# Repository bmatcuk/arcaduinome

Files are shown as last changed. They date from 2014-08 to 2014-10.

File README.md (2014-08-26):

# arcaduinome
Arcaduinome is an [Arduino](http://www.arduino.cc/) based MIDI controller that uses arcade buttons for input. The name is a combination of Arcade, Arduino, and [Monome](http://monome.org/).

1. [Software](#software)
2. [Hardware](#hardware)
  1. [Schematic](#schematic)
  2. [Board PCB Layout](#board-pcb-layout)
3. [Arduino Firmware](#arduino-firmware)
4. [License](#license)

## Software
The ArduinoSketch directory contains the Arduino source code. It requires that you have the MIDI Library installed. The latest build (at time of writing) is included in this repo. You'll first need to install it into your Arduino app: Open the Arduino application and select Sketch -> Import Library -> Add Library, then select Arduino_MIDI_Library_v4.1.zip.

## Hardware
Arcaduinome is based around the [Arduino Uno](http://arduino.cc/en/Main/ArduinoBoardUno), third revision. Most of the other hardware components are to support the LEDs which light the arcade buttons. Each component links to a website where you could buy the part, but you can probably find most of these parts at a variety of distributors. A lot of these parts could be swapped out for similar parts. I've made some notes below about why I've chosen a specific part and whether or not you can use some other generic part.

Datasheets for some of these parts can be found in the `reference` directory of this repository.

* **[Arduino Uno R3](http://www.adafruit.com/products/50)**
    I highly recommend a 3rd Revision (R3) board here. The R3 board has a larger USB-to-serial microcontroller (Atmega16U2) which will be reprogrammed later. If you have an older R1 or R2 board, you'll need to reprogram the USB-to-serial microcontroller every time you need to switch between MIDI and Arduino mode. Very annoying. With the R3, you just jumper two pins to switch back to Arduino mode.

* **16x [Sanwa OBSC 24 CW](http://www.paradisearcadeshop.com/sanwa-obsc-24mm-translucent-pushbuttons/689-sanwa-obsc-24-cw.html)**
    Any arcade button will do. Sanwa buttons are extremely popular with arcade cabinet and fighting game enthusiasts for their quick response and high-reliability. However, the buttons might be the most expensive part, so you can save a bit with some cheaper buttons. Just make sure they are translucent/transparent.

* **[Protoshield for Arduino](http://www.adafruit.com/products/51)**
    This part is optional. I like using the protoshield to break out the IO pins from the Arduino and it gives me a nice area to solder everything together. Plus, it's compact.

* **16x [Common Anode RGB LEDs](http://www.adafruit.com/products/302)**
    Theoretically, any RGB LEDs will do, as long as they are common-anode. You may need to adjust resistor values depending on the forward voltage of the LEDs you pick. Link goes to a 25-pack that's actually cheaper, I've found, than buying 16 discrete LEDs from other distributors. So save some money and you'll have 9 extra LEDs for your next project! Woot!

* **[Sanken SLA5086 - 5x P-Channel FET Array](http://www.digikey.com/product-search/en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)**
    The P-Channel FETs are used on the "high-side" of the LEDs to turn on the "rows". FETs are well-suited for this switching application, specifically P-Channels for the high-side. If every LED in a row is turned on, the high-side switch must be able to source ~0.24A. This part can handle 5A, so no problems there. Additionally, this particular part has a low (logic level) gate-threshold voltage, which means that it should fully "turn on" easily from the Arduino IO pin. All around, a good fit, and the hardest part to find alternatives for, unless you don't mind dealing with surface mount components. We're only going to use 4 of the 5 PFETs in this package, since we only have 4 rows of LEDs. And we're also going to use these rows to multiplex our buttons. This way, we only need to use 4 inputs for the 16 buttons.

* **2x [STMicroelectronics STPIC6D595B1R 8-bit Shift Register](http://www.digikey.com/product-detail/en/STPIC6D595B1R/497-6328-5-ND/1762207)**
    The shift registers are used on the "low-side" of the LEDs to control individual LEDs (ie, the columns). We need 2 of these because we have "12" LEDs per row (each RGB LED is basically like 3 LEDs - we have 4 RGB LEDs per row, so, 4 x 3 = 12). The two ICs are "daisy chained" to make a 16-bit shift register; we just ignore the last 4-bits since we only need 12. Each pin of the shift register must be able to sink 20mA, and, if every LED in the row is "on", the IC as a whole must be able to sink 8 x 20mA = 160mA. This IC can easily handle that with it's open-drain outputs. Additionally, the outputs are latched, which the code takes advantage of.

* **16x [NXP Semiconductors 1N4148,113 Standard Diode](http://www.digikey.com/product-detail/en/1N4148,113/568-1360-1-ND/763357)**
    Use any standard diodes you want, though lower forward voltages are preferable. These are just used to ensure that the buttons don't interfere with each other if you press two at the same time... particularly if they are in different rows.

* **8x [120 Ohm Resistors](http://www.digikey.com/product-detail/en/CFM14JT120R/S120QCT-ND/2617666)**
    Use any standard 120 Ohm resistors you like. These limit current through the green and blue sections of the RGB LEDs. If you use different RGB LEDs, make sure to use appropriate resistors! The RGB LEDs I'm using have a 3.2V forward voltage for the green and blue sections, so these resistors should limit current to somewhere around 15mA.

* **4x [220 Ohm Resistors](http://www.digikey.com/product-detail/en/CF14JT220R/CF14JT220RCT-ND/1830334)**
    Use any standard 220 Ohm resistors you like. These limit current through the red section of the RGB LEDs. If you use different RGB LEDs, make sure to use appropriate resistors! The RGB LEDs I'm using have a 1.8V forward voltage for the red section, so these resistors should limit current to somewhere around 15mA.

* **9x 4.7 kOhm Resistors**
    I had some of these laying around, so I don't have a link for them. The value is not very important, so any value around 4.7k is fine if you happen to have some resistors laying around, too. Though, you shouldn't have any trouble finding them on Digikey (or similar sites). These are just used as pull-up resistors for the Gates of the PFETs, and pull-down resistors for the buttons. The pull-up resistors will cause the PFETs to be shut-off when the circuit is first powered up, and the pull-down resistors will cause the Arduino to read 0's for the buttons until they are pressed. We need 5 of these resistors for the 5 PFETs in our array package (even though we are only using 4 of those PFETs, we want to make sure the 5th is "turned off"), and 4 resistors for the multiplexed buttons.

* **[12-pin SIP Socket](http://www.digikey.com/product-detail/en/643644-3/A29107-ND/294602)**
    Socket for the P-Channel FET Array - if you decide on some other high-side solution, you might not need this.

* **2x [16-pin DIP Socket](http://www.digikey.com/product-detail/en/A16-LC-TR-R/AE9994-ND/821748)**
    Sockets for the low-side shift registers - if you decide on some other low-side solution, you might not need this.

### Schematic

This is the full schematic for the Arcaduinome:

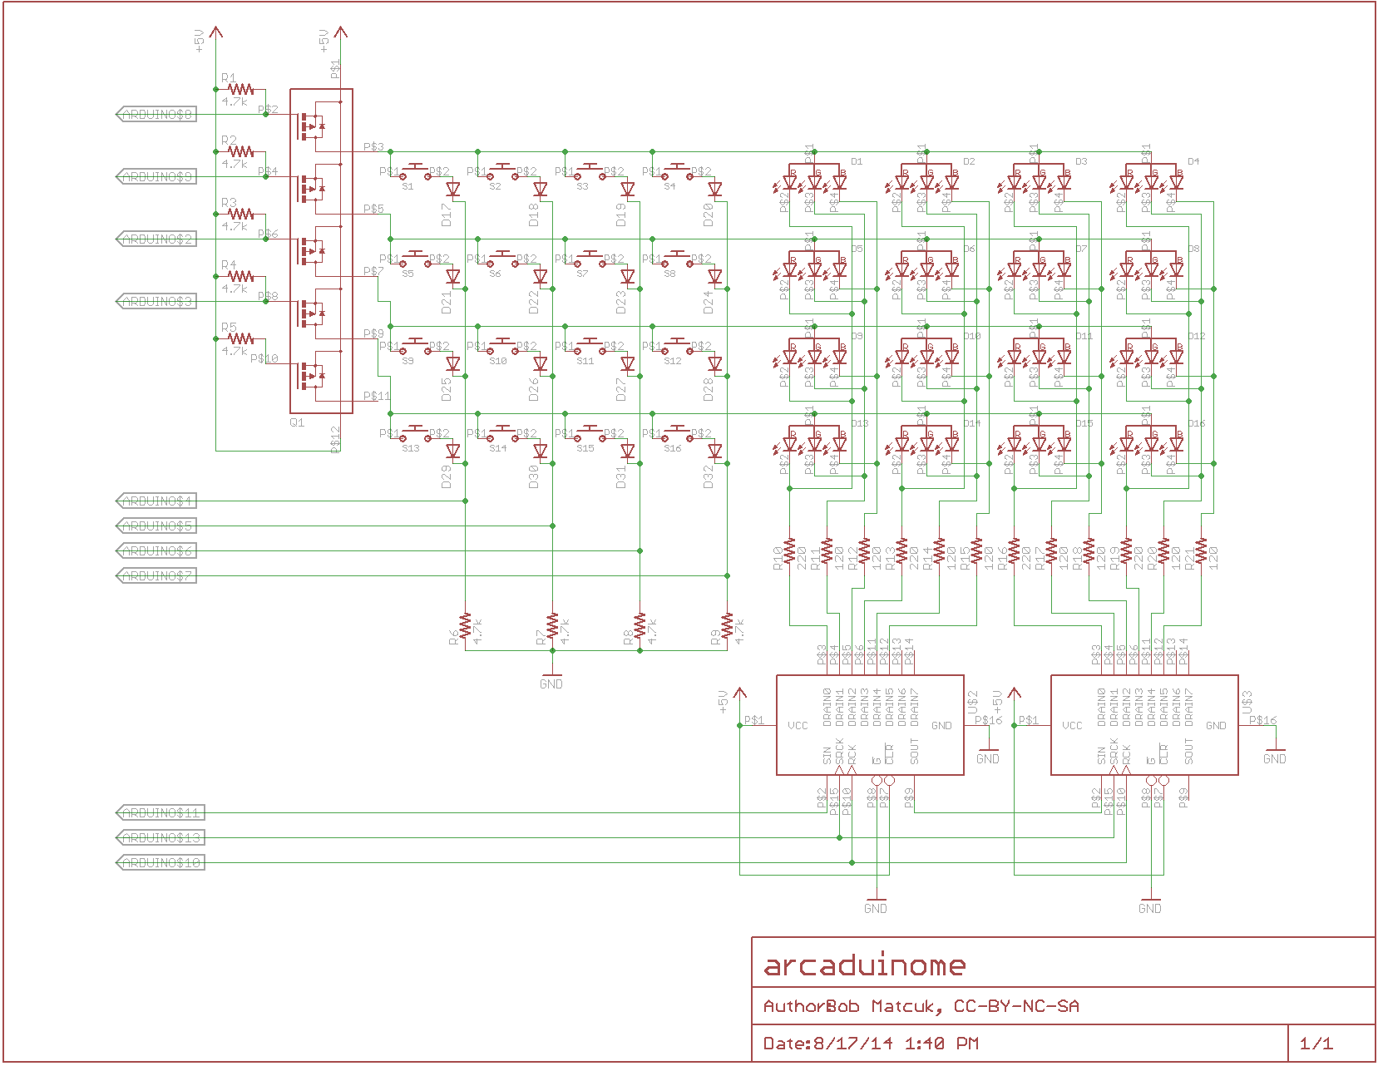
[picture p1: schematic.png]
Arcaduinome Schematic


However, due to limitations in the free version of Eagle and the fact that my PCB-manufacturer-of-choice is going to require that I order at least 3 boards anyway, I designed a smaller board that houses 4 buttons, with associated LEDs, resistors, and diodes, and a shift register:

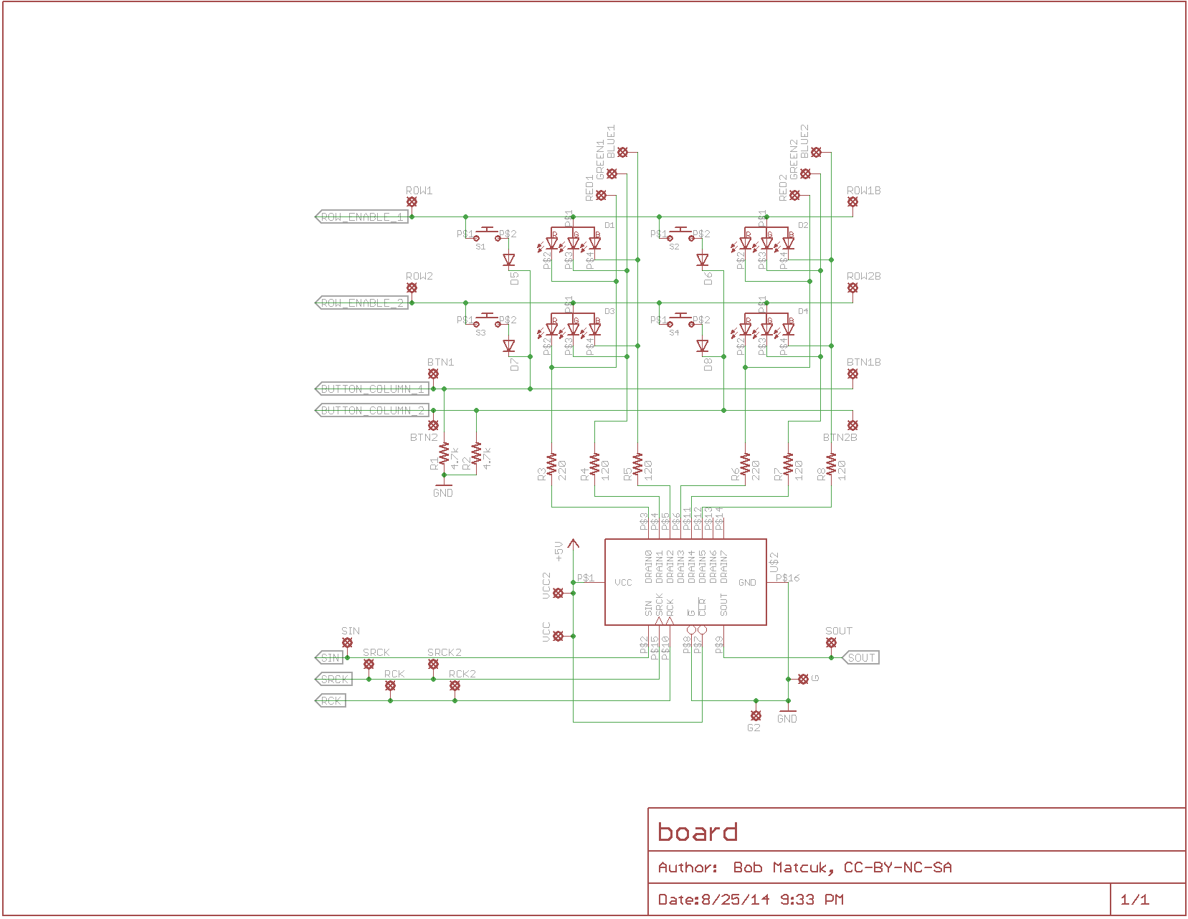
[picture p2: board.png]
Arcaduinome Board Schematic


The idea is that four of these boards would be used: the two boards at the "bottom" will house the shift registers. The two boards at the "top" will not have shift registers and, instead, use jumpers to connect to the boards on the "bottom". Similarly, jumpers are used to connect boards from left to right.

These schematics were generated using the free version of [Eagle v7.1](http://www.cadsoftusa.com/). The files are available in the `eagle` directory of this repository.

### Board PCB Layout

This is the layout of the smaller board I designed:

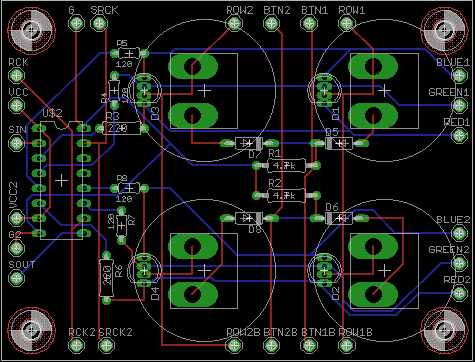
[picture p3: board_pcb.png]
Arcaduinome Board Layout


This layout was generated using the free version of [Eagle v7.1](http://www.cadsoftusa.com/). The files are available in the `eagle` directory of this repository.

## Arduino Firmware
The Arduino Uno R3 uses a microcontroller, specifically the Atmega16U2, as a USB-to-Serial adapter. Arcaduinome takes advantage of this fact using the [Moco](http://morecatlab.akiba.coocan.jp/lab/index.php/aruino/midi-firmware-for-arduino-uno-moco/?lang=en) (aka dualMocoLUFA) firmware. The latest version (at the time of writing) is included in this repo as dualMoco.hex. Installing this firmware on the Atmega16U2 will cause the Arduino to appear as a generic MIDI device to Windows/OSX. This way, we won't need any special drivers to interface with Arcaduinome.

To install the firmware into the Atmega16U2, follow the [DFU Programming Directions](http://arduino.cc/en/Hacking/DFUProgramming8U2) on Arduino's website. Once the new firmware has been installed, it will appear as a generic MIDI device when connected to your computer. You will no longer be able to use it as an Arduino (in other words, you won't be able to reprogram it). However, if you want to reenable Arduino mode, disconnect the Arduino from your computer, connect a jumper between pin 4 and 6 on the ICSP header, and reconnect to your computer. It should now appear as a normal Arduino Uno. When you're done reprogramming, disconnect from your computer, remove the jumper, and reconnect - it will now appear as a MIDI device again!

## License
This work is licensed under a [Creative Commons Attribution-NonCommercial-ShareAlike 4.0 International License](http://creativecommons.org/licenses/by-nc-sa/4.0/)



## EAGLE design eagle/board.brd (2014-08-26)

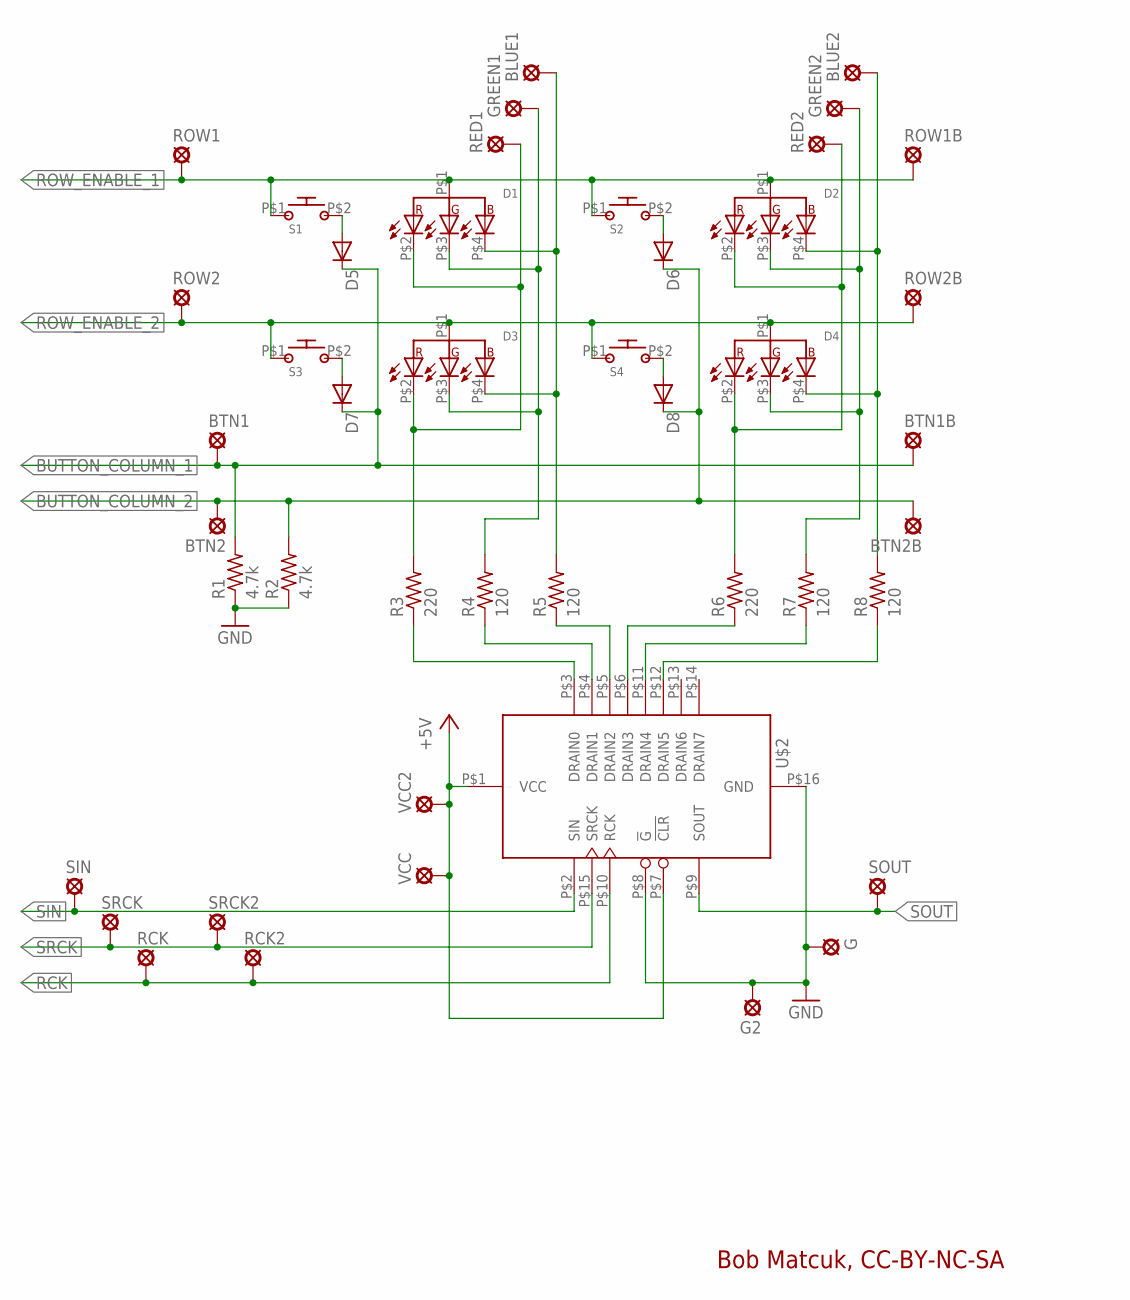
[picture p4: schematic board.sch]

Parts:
BLUE1, BLUE2: MCS10B
BTN1, BTN1B, BTN2, BTN2B: MCS10B
D1, D2, D3, D4: FD-5WSRGB-A; 5MM_RGB_LED
D5, D6, D7, D8: 1N4148DO35-7; DO35-7
G, G2: MCS10B
GREEN1, GREEN2: MCS10B
R1, R2: 4.7k; 0207/10
R3, R6: 220; 0207/7
R4, R5, R7, R8: 120; 0204/5
RCK, RCK2: MCS10B
RED1, RED2: MCS10B
ROW1, ROW1B, ROW2, ROW2B: MCS10B
S1, S2, S3, S4: SANWA_OBSC_24_CW; SANWA_24MM
SIN: MCS10B
SOUT: MCS10B
SRCK, SRCK2: MCS10B
U$2: STPIC6D595; DIP16
VCC, VCC2: MCS10B

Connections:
+5V: U$2.P$1 (VCC), U$2.P$7 (!CLR), VCC.MP, VCC2.MP
BUTTON_COLUMN_1: BTN1.MP, BTN1B.MP, D5.C, D7.C, R1.2
BUTTON_COLUMN_2: BTN2.MP, BTN2B.MP, D6.C, D8.C, R2.2
GND: G.MP, G2.MP, R1.1, R2.1, U$2.P$8 (!G), U$2.P$16 (GND)
unnamed: D5.A, S1.P$2
unnamed: D1.P$2 (R), D3.P$2 (R), R3.2, RED1.MP
unnamed: D1.P$3 (G), D3.P$3 (G), GREEN1.MP, R4.2
unnamed: BLUE1.MP, D1.P$4 (B), D3.P$4 (B), R5.2
unnamed: R5.1, U$2.P$5 (DRAIN2)
unnamed: D6.A, S2.P$2
unnamed: R4.1, U$2.P$4 (DRAIN1)
unnamed: D2.P$2 (R), D4.P$2 (R), R6.2, RED2.MP
unnamed: D2.P$3 (G), D4.P$3 (G), GREEN2.MP, R7.2
unnamed: BLUE2.MP, D2.P$4 (B), D4.P$4 (B), R8.2
unnamed: R3.1, U$2.P$3 (DRAIN0)
unnamed: D7.A, S3.P$2
unnamed: D8.A, S4.P$2
unnamed: R6.1, U$2.P$6 (DRAIN3)
unnamed: R7.1, U$2.P$11 (DRAIN4)
unnamed: R8.1, U$2.P$12 (DRAIN5)
RCK: RCK.MP, RCK2.MP, U$2.P$10 (RCK)
ROW_ENABLE_1: D1.P$1 (ANODE), D2.P$1 (ANODE), ROW1.MP, ROW1B.MP, S1.P$1, S2.P$1
ROW_ENABLE_2: D3.P$1 (ANODE), D4.P$1 (ANODE), ROW2.MP, ROW2B.MP, S3.P$1, S4.P$1
SIN: SIN.MP, U$2.P$2 (SIN)
SOUT: SOUT.MP, U$2.P$9 (SOUT)
SRCK: SRCK.MP, SRCK2.MP, U$2.P$15 (SRCK)

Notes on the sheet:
Bob Matcuk, CC-BY-NC-SA

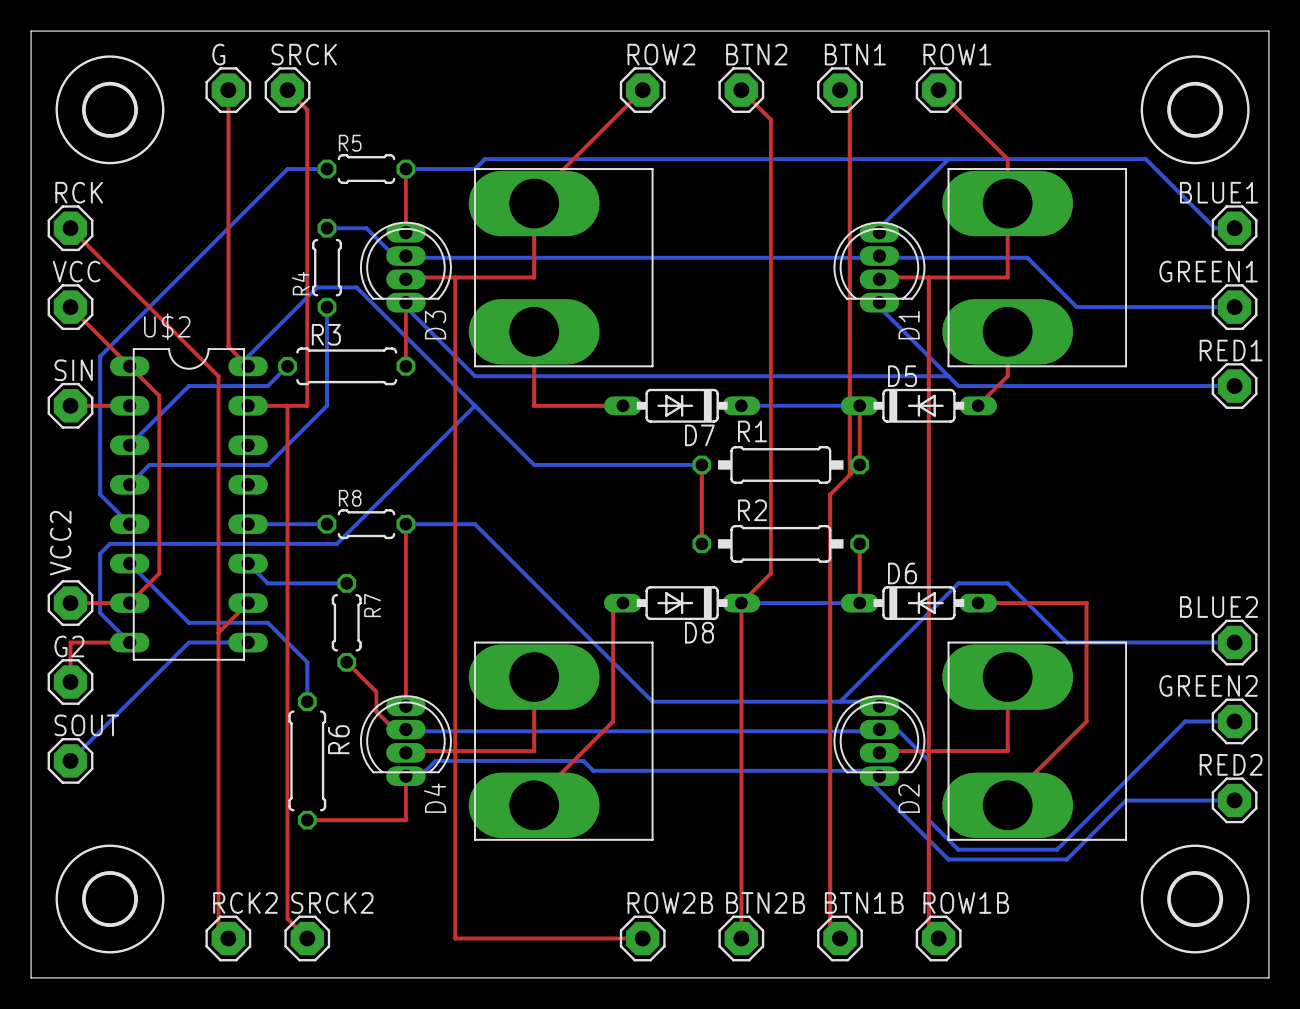
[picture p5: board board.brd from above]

Board: 2 copper layers, 79.7 x 61.0 mm, 49 parts (0 on the bottom side), 26 nets.

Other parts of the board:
U$3, U$4, U$5, U$6: 3,2

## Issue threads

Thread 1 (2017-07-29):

Still active?

ayman0201, 2017-07-29:
Hi,

I know the project is 3 years old, but I was still interested in implementing it.
I was trying the eagle folder files and none of them opened on eagle 7.1
Have you tried porting them into a newer version?

bmatcuk, 2017-07-29:
Hey there,

Thanks for the interest! Unfortunately, I never quite finished this project =( I'd really like to finish it up at some point, but I can't seem to find the time. It needs a lot of work: I think the Arduino code can only turn on the LEDs to preset colors, and there's some debounce code for the buttons, but that's about it. I really wanted to make the colors programmable, and I needed to write the MIDI stuff. Then I needed a desktop app that could be used to set the colors and notes - I didn't even start that. I was also thinking of redesigning the boards to use wires to the buttons, instead of trying to solder the buttons directly to the boards; I think that would make building it easier. And I wanted to design a 3D printed box for the whole thing. So many ideas, so little time =(

Man, I should really finish this...

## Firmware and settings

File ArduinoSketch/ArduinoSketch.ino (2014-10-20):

/*******************************************************************************
Arcaduinome Arduino Sketch
- Bob Matcuk, 2014

This code eschews things like pinMode and digitalWrite for speed reasons, and,
instead, accesses the registers directly using bit-wise operators. It's not
meant to look pretty; it's meant to handle the LEDs as quickly as possible,
since the MIDI stuff is much more important. Hopefully it's documented well
enough that you can follow along! =)

Atmega pin to Arduino mapping: http://arduino.cc/en/Hacking/PinMapping168
Arduino pin description: http://www.gammon.com.au/forum/?id=11473

TODO: buttons - http://www.ganssle.com/debouncing-pt2.htm (listing 3)
*******************************************************************************/

#include <EEPROM.h>
#include <MIDI.h>
#include <midi_Defs.h>
#include <midi_Namespace.h>
#include <midi_Settings.h>

// if defined, disables MIDI and just prints stuff to serial
//#define DEBUG 1

// The MIDI manufacturer ID is used to determine if a sysex message is
// destined for us. 0x7D is specifically reserved for "educational use", so it
// shouldn't be used by any commercial product. However, if you find that this
// is causing some problems with some other MIDI equipment, you might need to
// change this. The code does NOT support extended Manufacturer IDs (the MIDI
// spec includes support for an ID of 0x00 which means that the next two bytes
// are the actual ID), but it could be added...
#define MIDI_MANUFACTURER_ID 0x7D

// Sysex message IDs
#define SYSEX_SET_ALL_LEDS 0x00
#define SYSEX_SET_LED      0x01
#define SYSEX_SAVE_LEDS    0x02
#define SYSEX_RESET_LEDS   0x03

#define SYSEX_SET_ALL_BUTTONS 0x10
#define SYSEX_SET_BUTTON      0x11
#define SYSEX_SAVE_BUTTONS    0x12
#define SYSEX_RESET_BUTTONS   0x13

// Offsets in EEPROM for LED and Button settings
#define EEPROM_LED_OFFSET    0x0000
#define EEPROM_BUTTON_OFFSET (EEPROM_LED_OFFSET + 4 * 12)

// Multiplexed "rows" are controlled via the high-side P-channel FET Array.
// Only one row may be turned on at a time. Row 1 and 2 are controlled by
// Port B, pins 0 and 1. Row 3 and 4 are controlled by Port D, pins 2 and 3.
// To turn "on" a row, the corresponding pin must be brought LOW. Therefore,
// ROW_ENABLES has negated the masks already so they can be AND'd.
#define ROW1_ENABLE_MASK _BV(0)   // Arduino pin 8 = Port B, pin 0
#define ROW2_ENABLE_MASK _BV(1)   // Arduino pin 9 = Port B, pin 1
#define ROW3_ENABLE_MASK _BV(2)   // Arduino pin 2 = Port D, pin 2
#define ROW4_ENABLE_MASK _BV(3)   // Arduino pin 3 = Port D, pin 3
const byte ROW_ENABLES[] = {
  ~ROW1_ENABLE_MASK,
  ~ROW2_ENABLE_MASK,
  ~ROW3_ENABLE_MASK,
  ~ROW4_ENABLE_MASK
};

// SPI settings for the SPI Control Register:
// 0  = disable SPI Interupt
// 1  = enable SPI
// 1  = transfer LSB first
// 1  = master mode
// 0  = idle clock is low and pulses high
// 0  = sample on the leading edge of the clock
// 00 = speed is clock/4 (set LSB of SPSR to a 1 to double speed)
#define SPI_SETTINGS B01110000

// SPI output pins - SCK, MOSI, and SS
// SCK  = Arduino pin 13 = Port B, pin 5
// MOSI = Arduino pin 11 = Port B, pin 3
// SS   = Arduino pin 10 = Port B, pin 2
#define SPI_OUTPUT_PINS (_BV(5) | _BV(3) | _BV(2))

// LED array - 4 rows by 12 columns arranged in RGB order
// ie: {{R1, G1, B1, R2, G2, B2, R3, G3, B3, R4, G4, B4}, {...}, ...}
byte leds[4][12];

// Button inputs are the four high bits of Port D.
#define BUTTON1_MASK _BV(4)   // Arduino pin 4 = Port D, pin 4
#define BUTTON2_MASK _BV(5)   // Arduino pin 5 = Port D, pin 5
#define BUTTON3_MASK _BV(6)   // Arduino pin 6 = Port D, pin 6
#define BUTTON4_MASK _BV(7)   // Arduino pin 7 = Port D, pin 7
#define BUTTON_MASK  (BUTTON1_MASK | BUTTON2_MASK | BUTTON3_MASK | BUTTON4_MASK)
const byte BUTTON_MASKS[] = {
  BUTTON1_MASK,
  BUTTON2_MASK,
  BUTTON3_MASK,
  BUTTON4_MASK
};

// Debouncing array for buttons: the first dimension of the array represents
// rows. The second is a circular queue representing the last X many readings
// from Port D (where the buttons are - see above). X is DEBOUNCING_CHECKS
// and MUST be a power of 2. If all of these readings are identical, that
// means the user really did press (or release) the button. button_index
// holds the current index into the circular queue. Once it hits the maximum
// (DEBOUNCING_CHECKS), it will wrap back to zero.
#define DEBOUNCING_CHECKS 16
byte button_debounce[4][DEBOUNCING_CHECKS];
byte button_index = 0;

// We also keep track of the current state of the buttons... The cooresponding
// bit will be a 1 if we have already decided the button was pressed and sent
// the cooresponding "NoteOn" command. It'll be a zero if we think the button
// hasn't been pressed.
byte button_state[4];

// This array holds the note that a button should make when it is pressed.
byte buttons[4][4];


void setup()
{
  // Set "row" pins as output and turn them all off for now (by setting the
  // pins high). We set the pins high first, which will engage the internal
  // pull-up resistors since they're still in "input" mode. Externally, we
  // have more pull up resistors, so nothing will really happen. Then when
  // we switch to output mode, the pins will already be pulled high so more
  // nothing will happen - exactly as we planned =)
  PORTB |= ROW1_ENABLE_MASK | ROW2_ENABLE_MASK;
  DDRB |= ROW1_ENABLE_MASK | ROW2_ENABLE_MASK;
  PORTD |= ROW3_ENABLE_MASK | ROW4_ENABLE_MASK;
  DDRD |= ROW3_ENABLE_MASK | ROW4_ENABLE_MASK;
  
  // Set SPI pins to output and bring SS (Port B, pin 2) low
  DDRB |= SPI_OUTPUT_PINS;
  PORTB &= ~_BV(2);
  
  // Setup SPI to communicate with the shift registers for "columns"
  // The STPIC6D595B1R shift registers recommend a clock duration of at least
  // 40ns = 25MHz. The fastest SPI clock on the Arduino is clock/2 = 8MHz,
  // which is slower than the quickest clock the shift registers can handle.
  // To achieve clock/2, we must also set the LSB of SPSR to 1 to enable
  // "double speed". Ideas stolen from SPI library source:
  // https://github.com/arduino/Arduino/blob/master/libraries/SPI/SPI.cpp
  // https://github.com/arduino/Arduino/blob/master/libraries/SPI/SPI.h
  SPCR = SPI_SETTINGS;
  SPSR |= _BV(0);
  
  // Setup button input pins - shouldn't really need to do this, since
  // input is default... but for completeness...
  DDRD &= ~BUTTON_MASK;
  
  // Enable MIDI
#ifdef DEBUG
  Serial.begin(115200);
#else
  MIDI.begin();
  MIDI.turnThruOff();
  MIDI.setHandleSystemExclusive(handleSystemExclusive);
#endif
  
  // load LEDs from EEPROM
  //for (byte row = 0; row < 4; row++) {
  //  for (byte column = 0; column < 12; column++) {
  //    leds[row][column] = EEPROM.read(EEPROM_LED_OFFSET + (12 * row) + column);
  //  }
  //}
  
  // TODO: remove and uncomment above!
  // for testing, let's give the LED some colors!
  for (byte row = 0; row < 4; row++) {
    for (byte column = 0; column < 4; column++) {
      leds[row][column*3]   = min(256 - row * 64, 255);      // R
      leds[row][column*3+1] = min(256 - column * 64, 255);   // G
      leds[row][column*3+2] = 255;                           // B
    }
  }
  
  // zero out debouncing, button state, and load buttons
  for (byte row = 0; row < 4; row++) {
    button_state[row] = 0;
    for (byte column = 0; column < 4; column++)
      buttons[row][column] = 0;   // TODO: EEPROM.read(EEPROM_BUTTON_OFFSET + (4 * row) + column);
    for (byte checks = 0; checks < DEBOUNCING_CHECKS; checks++)
      button_debounce[row][checks] = 0;
  }
}

void handleSystemExclusive(byte *array, byte size)
{
  // array[0] will be 0xF0 which starts the sysex message
  // array[1] will be the manufacturer ID - ignore the message if it
  //   doesn't match our manufacturer ID
  // array[2] will be the operation, assuming the message is for us
  // array[3..size-2] will be the data encoded using the following scheme:
  //   bytes evenly divisible by 8 (0, 8, 16, ...) will represent the MSb
  //   of the following 7 bytes, with the LSb corresponding to the first
  //   byte, and the MSb corresponding to the 7th byte. This is because
  //   the MIDI standard reserves bytes that have the MSb set. This scheme
  //   allows us to encode values greater than 127 and is, conveniently,
  //   implemented by the Arduino MIDI library.
  // array[size-1] is 0xF7, the MIDI code for "end of sysex"
  // size includes the 0xF0 "start sysex" code, the manufacturer ID,
  //   the operation code, and the terminating 0xF7 code, so the actual
  //   data length is size - 4 starting at array + 3.
  if (array[1] == MIDI_MANUFACTURER_ID) {
    if (array[2] == SYSEX_SET_ALL_LEDS) {
      // Set All LEDs
      // leds is a 2D array, but C lays out 2D arrays like 1D arrays, so
      // we trick it into dumping the data in with a cast.
      midi::decodeSysEx(array + 3, (byte*)leds, size - 4);
    } else if (array[2] == SYSEX_SET_LED) {
      // Set an Individual LED Color
      // array[3..6] is R,G,B for the LED, encoded as described above (hence
      //   the extra byte)
      // array[7] is the row
      // array[8] is the column
      // Technically, array[7] and array[8] are part of the encoding as
      // described above, but since both row and column will be less than 4,
      // we don't need to worry about decoding their MSb.
      midi::decodeSysEx(array + 3, (byte*)leds + (12 * array[7] + 3 * array[8]), 4);
    } else if (array[3] == SYSEX_SAVE_LEDS) {
      // Save the LED Colors to the EEPROM
      for (byte i = 0; i < 4; i++) {
        for (byte j = 0; j < 12; j++) {
          EEPROM.write(EEPROM_LED_OFFSET + (12 * i) + j, leds[i][j]);
        }
      }
    } else if (array[3] == SYSEX_RESET_LEDS) {
      // Reset the LEDs from the EEPROM
      for (byte i = 0; i < 4; i++) {
        for (byte j = 0; j < 12; j++) {
          leds[i][j] = EEPROM.read(EEPROM_LED_OFFSET + (12 * i) + j);
        }
      }
    } else if (array[3] == SYSEX_SET_ALL_BUTTONS) {
      // Set All Buttons
      // buttons in a 2D array, but C lays out 2D arrays like 1D arrays, so
      // we trick it into dumping the data in with a cast.
      midi::decodeSysEx(array + 3, (byte*)buttons, size - 4);
    } else if (array[3] == SYSEX_SET_BUTTON) {
      // Set an Individual Button
      // array[3] will always be zero as a result of encoding
      // array[4] will be the note to use for the button
      // array[5] is the row
      // array[6] is the column
      buttons[array[5]][array[6]] = array[4];
    } else if (array[3] == SYSEX_SAVE_BUTTONS) {
      // Save the Buttons to the EEPROM
      for (byte i = 0; i < 4; i++) {
        for (byte j = 0; j < 4; j++) {
          EEPROM.write(EEPROM_BUTTON_OFFSET + (4 * i) + j, buttons[i][j]);
        }
      }
    } else if (array[3] == SYSEX_RESET_BUTTONS) {
      // Reset the buttons from the EEPROM
      for (byte i = 0; i < 4; i++) {
        for (byte j = 0; j < 4; j++) {
          buttons[i][j] = EEPROM.read(EEPROM_BUTTON_OFFSET + (4 * i) + j);
        }
      }
    }
  }
}

void loop()
{
  // The iteration count is used to vary LED intensity. If we have a red
  // value of 128, for example, we only turn that LED "on" for the first
  // half of the passes through the main loop. It's kind of like a poor
  // man's PWM.
  static byte last_row = 3, row = 0, iteration_count = 0;
  
  // read MIDI data
#ifdef DEBUG
#else
  MIDI.read();
#endif
  
  // The shift registers are configured so that RGB LED 1 is on pins
  // 0 = R, 1 = G, 2 = B of the first shift register. RGB LED 2 is also
  // on the first shift register, pins 3, 4, and 5 in the same order.
  // RGB LED 3 is on pins 0-2 of the second register, and RGB LED 4 is
  // on pins 3-5. The first byte that we shift out will be destined for
  // the second shift register. Since we are shifting out LSB first, we
  // want column 11 (RGB LED #4, blue channel) to end up setting bit 2.
  // Column 10 (RGB LED #3, green channel) should set bit 3, and so on.
  // This means we use 13 - column to calculate the bit position.
  byte column_data = 0, column = 11;
  for (; column >= 6; column--) {
    if (leds[row][column] > iteration_count)
      column_data |= 1 << (13 - column);
  }
  SPDR = column_data;
  
  // Build second byte while the first one is transferring. This will
  // be the byte destined for the first shift register. We want column
  // 5 (RGB LED #2, blue channel) to end up setting bit 2. Column 4
  // (RGB LED #2, green channel) should set bit 3, and so on. Because
  // we shift out LSB first, this means we use 7 - column to calculate
  // the bit positions.
  column_data = 0;
  for (; column >= 0; column--) {
    if (leds[row][column] > iteration_count)
      column_data |= 1 << (7 - column);
  }
  
  // Wait for first byte to finish (do we need this?) then start
  // sending the second byte of column data. SPI Flag (bit 7 in the
  // SPI Status Register) will go high when SPI is done transferring.
  while (!(SPSR & _BV(7)));
  SPDR = column_data;
  
  // While we wait for the second byte to transfer, let's check our
  // buttons, shall we? Currently, the previous "row" will still have
  // power, since we haven't turned it off yet (that happens below).
  // pressed_buttons is initialized so that we'll only get a 1 for the
  // buttons that we didn't already know were pressed. Likewise,
  // released_buttons will have a 0 for buttons we didn't already know
  // were released - we negate it after the loop so it'll have 1's instead.
  byte pressed_buttons = BUTTON_MASK & ~button_state[last_row];
  byte released_buttons = ~BUTTON_MASK | ~button_state[last_row];
  button_debounce[last_row][button_index] = PORTD;
  for (byte i = 0; i < DEBOUNCING_CHECKS; i++) {
    pressed_buttons &= button_debounce[last_row][i];
    released_buttons |= ~button_debounce[last_row][i];
  }
  released_buttons = ~released_buttons;
  
  // If pressed_buttons is non-zero, we have a newly pressed button!
  if (pressed_buttons) {
    for (byte column = 0; column < 4; column++) {
      if (pressed_buttons & BUTTON_MASKS[column]) {
        button_state[last_row] |= BUTTON_MASKS[column];
#ifdef DEBUG
        Serial.print("ON ");
        Serial.print(buttons[last_row][column], HEX);
        Serial.print("\n");
#else
        MIDI.sendNoteOn(buttons[last_row][column], 127, 1);
#endif
      }
    }
  }
  
  // if released_buttons is non-zero, we have a newly released button!
  if (released_buttons) {
    for (byte column = 0; column < 4; column++) {
      if (released_buttons & BUTTON_MASKS[column]) {
        button_state[last_row] &= ~BUTTON_MASKS[column];
#ifdef DEBUG
        Serial.print("OFF ");
        Serial.print(buttons[last_row][column], HEX);
        Serial.print("\n");
#else
        MIDI.sendNoteOff(buttons[last_row][column], 127, 1);
#endif
      }
    }
  }
  
  // Make sure we're done sending the second byte via SPI and disable all rows.
  // Probably don't need to check SPI here, since the previous part will take
  // a pretty long time... but just to be safe... Remember, disabling a row
  // means that we pull the pin "high"!!
  while (!(SPSR & _BV(7)));
  PORTB |= ROW1_ENABLE_MASK | ROW2_ENABLE_MASK;
  PORTD |= ROW3_ENABLE_MASK | ROW4_ENABLE_MASK;
  
  // We've connected the SS pin (Port B, pin 2) to the latch clock on the
  // shift registers. Here we strobe the pin to cause the shift registers
  // to latch on the new values. The data sheet for the shift registers
  // recommends that the latch clock stays high for at least 40ns.
  // The Arduino is operating at 8MHz which means the pin should stay
  // high for at least 125ns, even if we turn it back off "immediately".
  PORTB |= _BV(2);
  PORTB &= ~_BV(2);
  
  // Enable the row - the first two rows (0 and 1) are on Port B,
  // but the second rows (2 and 3) are on Port D. Remember, enabling the
  // row means we pull the pin "low"!!
  if (row & B00000010)
    PORTD &= ROW_ENABLES[row];   // we're on row 2 or 3
  else
    PORTB &= ROW_ENABLES[row];   // we're on row 0 or 1
  
  // Set the last_row to the current row, and, if the current row is zero,
  // increment the button_index.
  last_row = row;
  if (!last_row)
    button_index = (button_index + 1) & (DEBOUNCING_CHECKS - 1);
  
  // increment the row counter, but wrap 4 back to 0
  // also increment the iteration_count
  row = (row + 1) & B00000011;
  iteration_count++;
}

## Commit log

2014-06-02 beginning of the Arduino code
2014-06-04 more arduino code
2014-06-06 leds might work? No way to set colors though
2014-06-08 some SPI research - may want to replace SPI library with straight register manipulation for speed
    [ArduinoSketch.ino]
2014-06-09 reference data sheets for arduino, FET array, shift registers, and leds
2014-06-09 reworked SPI to directly access registers for speed
    [ArduinoSketch.ino]
2014-06-10 started some button stuff
2014-06-10 most of the button handling is done - just need to send MIDI commands
2014-07-11 started schematic drawing
    [arcaduinome.sch]
2014-07-11 updated SLA5086
    [arcaduinome.sch]
2014-07-16 finished SLA5086 component
    [arcaduinome.sch]
2014-07-18 added arduino and rgb led compenents; started placing components on schematic
    [arcaduinome.sch]
2014-08-07 started eagle schematic
    [arcaduinome.sch]
2014-08-17 added RGB LEDs
2014-08-17 added resistors
2014-08-17 added Sanwa buttons
2014-08-17 made schematic
    [arcaduinome.sch]
2014-08-18 removed that kicad nonsense
    [arcaduinome.sch]
2014-08-18 added datasheets for resistors and diodes
2014-08-18 added schematic, TOC
2014-08-26 PCB layout
    [board.brd, board.sch]
2014-10-20 support for setting leds/buttons via sysex; note on/off
